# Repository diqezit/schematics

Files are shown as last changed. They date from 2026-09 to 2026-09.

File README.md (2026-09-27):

<details>
<summary><b>Русская версия README</b></summary>

# FMradio

ЧМ-приёмник на дискретных транзисторах с низкой промежуточной частотой, зарядовым частотным детектором, варикапной настройкой, автоматической подстройкой частоты и УНЧ на LM386.

- Диапазон: 88-108 МГц
- Питание: +9 В
- Нагрузка: 8 Ом
- Целевой размер платы: 50 x 70 мм
- Ток покоя тракта до УНЧ: около 23 мА

> Статус: инженерный разбор схемы и наброска печатной платы. Источник истины по номиналам и режимам - LTspice, файл `Fm.asc` (ревизия 05). Файл Multisim `Fm.ms14` сохранён как историческая ссылка предварительной серии ревизии 01 и для сверки топологии KiCad. Это не подтверждение работоспособности готового устройства и не комплект для изготовления.

Изменения ревизии 05:

1. Варикапы D1 входного контура и D5 гетеродина заменены с BB112 на BB844. Принята модель Cjo = 120 пФ, Vj = 0,75 В, M = 1,35. Расчётная кривая C(V) сверена с опорной таблицей, отклонение меньше 1 %.
2. Транзистор гетеродина 2N5401 заменён на BFT92. Для 2N5401 с fT = 300 МГц запуска на 101,9 МГц не получено из-за недостаточного запаса по граничной частоте. Для BFT92 паспортное fT равно 5 ГГц, упрощённая SPICE-модель даёт около 1 ГГц.
3. Пересчитаны контуры: L1 = 175 нГн, C3 = 4,1 пФ, C4 = 13,7 пФ; L2 = 138 нГн, C17 = 10 пФ, C18 = 36 пФ, C19 = 13,7 пФ.
4. Добавлена директива `.ic` для короткого окна звукового тракта без ожидания установления медленной петли АПЧ.
5. Нагрузка R22/C22 в АПЧ увеличена до R22 = 15 кОм и C22 = 47 мкФ. Расчётная постоянная времени составляет около 0,7 с.

Правило трёх документов. Номиналы и режимы нормативны по LTspice. Топология и посадочные места нормативны по KiCad. Расчётные формулы разделов 1-7 записаны в нумерации KiCad/README и сверяются с LTspice по таблице соответствия. Перенумерация KiCad под ревизию 05 запланирована; до её выполнения таблица соответствия нормативна.

Расчётные величины в основных разделах получены аналитически для режимов по постоянному току и RC-цепей при U_БЭ около 0,65 В и типичном h21э транзисторов. Результаты симуляции сведены в приложении, совпадения и расхождения с расчётом отмечены явно. Ни расчёт, ни симуляция не заменяют измерений на реальной плате.

## Схема

Принципиальная схема ЧМ-приёмника
Набросок схемы и платы

## Демонстрация работы

Сигнал ПЧ на выходе в симуляции

Снимок относится к одному из прогонов подгонки контуров ревизии 01 в Multisim и служит только иллюстрацией настройки. Рабочие данные ревизии 05 сняты в LTspice командой `.tran 0 12m 10m 1n`. Raw-файл или экспорт ключевых трасс следует хранить вместе с `Fm.asc`.

## Источники и воспроизводимость

- `Fm_radio.kicad_sch`: схема, KiCad 10.0, лист A3.
- `Fm_radio.kicad_pcb`: печатная плата, KiCad 10.0, два слоя меди F.Cu и B.Cu.
- `Fm_radio.kicad_pro`: настройки проекта, включая правила проверки платы.
- `Fm_radio.kicad_prl`: локальные настройки отображения.
- `Fm.asc`: файл симуляции LTspice, источник истины начиная с ревизии 02. Содержит нетлист, директивы `.tran`, `.op`, `.ic`, `.options`, модели диодов, варикапов и транзистора гетеродина.
- `Fm.ms14`: файл симуляции Multisim. Содержит экспорт предварительной серии ревизии 01 и замеры рабочей точки. Результаты ревизий 02-05 из него не воспроизводятся и не цитируются как текущие.

## Инструмент моделирования и соответствие ревизий

Начиная с ревизии 02 источником истины по номиналам и режимам является LTspice. Multisim оставлен как историческая ссылка ревизии 01 и средство сверки топологии KiCad.

LTspice выбран из-за доступных допусков интегрирования, именованных измерений, `.step`, `.meas`, `.op` и приемлемого времени расчёта. В Multisim непрерывные окна 300 мкс и 3 мс были практически недоступны, а встроенный частотомер давал ложные показания на узлах с амплитудой в десятки милливольт.

Модели LTspice, источник истины ревизии 05:

```text
.model BB844 D(Is=1e-14 Rs=0.28 N=1.0 Cjo=120p M=1.35 Vj=0.75 Fc=0.5
+ Bv=18 Ibv=10u Tt=0 Eg=1.11 Xti=3)

.model BFT92 PNP(IS=1E-14 BF=100 VAF=100 IKF=0.1 ISE=1E-13 NE=1.5
+ BR=4 IKR=0.1 ISC=1E-13 NC=1.5 RB=10 RE=1 RC=10
+ CJE=1.5P VJE=0.7 MJE=0.4 CJC=1P VJC=0.5 MJC=0.4
+ TF=0.15N TR=10N XTB=1.5 XTI=3 EG=1.11)

.model BZX55C6V8 D(Is=1e-14 N=1.1 Rs=3.5 Cjo=160p M=0.33 Vj=0.75 Bv=6.8 Ibv=5m Eg=1.11 Xti=3)
.model BZX55C3V3 D(Is=1e-14 N=1.1 Rs=15 Cjo=25p M=0.33 Vj=0.6 Bv=3.3 Ibv=5m)
```

Модель BB112 сохранена только для воспроизведения ревизии 04:

```text
.model BB112 D(Is=1e-14 Rs=0.7 N=1.2 Cjo=58p M=0.50 Vj=0.85 Fc=0.5 Bv=30 Ibv=10u Tt=0)
```

Упрощённая модель BFT92 с TF = 0,15 нс соответствует оценочному fT около 1 ГГц, а не паспортным 5 ГГц. Она подтверждает запуск в ревизии 05, но не заменяет модель производителя для оценки амплитуды, фазового шума и предельного режима. Имена библиотек остальных транзисторов и полные строки их SPICE-моделей в репозитории не зафиксированы, поэтому перед повторным прогоном модели следует сверить.

## Протокол прогонов

Нормативный короткий прогон ревизии 05:

```text
.tran 0 12m 10m 1n
.ic V(DETEC)=1.2 V(AFC)=1.2 V(FILT)=1.2 V(N010)=4.5 V(VZ_3V3)=3.3 V(VZ_6V8)=6.8
.options reltol=0.003 trtol=7 method=gear cshunt=1e-14 plotwinsize=0
```

Директива `.ic` задаёт начальные уровни детектора, АПЧ, фильтра, выхода LM386 и двух опорных шин. Она нужна для наблюдения последних 2 мс из окна 12 мс без ожидания установления петли АПЧ с постоянной времени около 0,7 с. Этот режим не доказывает захват АПЧ и не заменяет прогон без начальных условий.

Дополнительные прогоны:

- Рабочая точка: `.op` при V1 = 8/9/10 В, положении потенциометра 0/50/100 % и T = -10/25/50 C.
- ВЧ и ПЧ без принудительных начальных условий: не менее 300 мкс с максимальным шагом 1 нс.
- Звуковой тракт: не менее 20 мс либо до установления C25 = 330 мкФ и узла N010.
- АПЧ: 0,5-1 с без `.ic` или отдельная огибающая модель. Полный ВЧ-прогон с шагом 1 нс на таком интервале вычислительно тяжёл.
- Ограничитель: 3 мс с контролем VBE(VT5) не ниже -5 В и огибающей 1 кГц 280-400 мВ размаха.

## Нормативные пороги приёмки

Пороги ревизии 04 сохранены для исторического сравнения:

- меандр на коллекторе VT4 непрерывен до 300 мкс, без пачек и провалов;
- ток обратной связи УПЧ без дрейфа среднего;
- полка детектора 1,1-1,3 В;
- I(D6) 5-12 мА;
- V(REF) 6,4-7,2 В.

Нормативные пороги ревизии 05:

- размах на коллекторе Q6 1-2 В;
- ток эмиттера Q6 2-3 мА без двуполярных игл и выбросов;
- период импульсов ПЧ при MDI = 0 равен 2,35 +/- 0,05 мкс;
- полка детектора 1,1-1,3 В;
- I(D6) 5-12 мА;
- V(REF) 6,4-7,2 В;
- звуковой сигнал на нагрузке 8 Ом не меньше 1 В размаха после установления тракта.

Текущий прогон ревизии 05 проходит критерии периода ПЧ и полки детектора. Критерии амплитуды и тока гетеродина не пройдены. Ток D6 и установившиеся уровни опорных шин без `.ic` в предоставленных измерениях отсутствуют. Критерий звука не оценён, потому что V(N010) и C25 не установились в окне 12 мс.

## Блокеры до трассировки

- Перевозбуждение гетеродина. V(Q6_C) имеет размах 0-4 В, Ie(Q6) достигает примерно +/-6 мА. Требуется повторный расчёт смещения и коэффициента обратной связи BFT92. Плату до выбора проверенного режима не фиксировать.
- Сопряжение контуров. При одном управляющем напряжении разность резонансных частот L1 и L2 меняется примерно от 0,5 до 1,5 МГц вместо требуемых 425 кГц. Нужна раздельная коррекция ветвей D1 и D5 или подстроечные элементы.
- Ход настройки. Связка BB844 и 13,7 пФ в текущей модели даёт около 0,8 МГц, поэтому диапазон 88-108 МГц не перекрывается. Нужна коммутация L2, другой диапазон ёмкостей или отдельная грубая настройка.
- Сохраняется блокер ревизии 04: прогон 3 мс с VBE(VT5) не ниже -5 В ещё не выполнен.

Имена узлов вида n0XX не нормативны. Перед прогоном следует назначить метки A, B, REF, TUNE, Q1_E, Q2_B, Q3_B, Q4_C, Q5_C, Q6_C, DETEC, AFC, FILT, N010, SPK, VZ_3V3 и VZ_6V8.

## Таблица соответствия идентификаторов

Таблица нормативна до перенумерации KiCad.

| Назначение | KiCad/README | LTspice rev 05 | Номинал или тип |
|---|---|---|---|
| ВЧ-транзистор | VT1 2N5401 | Q1 2N5401 | режим без изменения |
| Смеситель | VT2 BF517 | Q2 2SC3838K | тип 2SC3838K |
| УПЧ 1 / УПЧ 2 | VT3 / VT4 BC547 | Q3 / Q4 BC547C | группа C |
| Ограничитель | VT5 BC547 | Q5 BC547C | группа C |
| Гетеродин | VT6 BFT92 | Q6 BFT92 | PNP, SOT-23 |
| Диоды детектора | VD1, VD2 1N4148 | D2, D3 1N4148 | без изменения |
| Опора настройки | VD3, R19 | D6 BZX55C6V8, R25 180 Ом | V(REF) около 6,86 В |
| Шина 3,3 В | VD4, R27 1 кОм | D4, R19 1 кОм | VZ_3V3 |
| Варикап входа | BB844, C4 13,7 пФ | D1 BB844, C4 13,7 пФ | Cjo = 120 пФ |
| Варикап гетеродина | BB844, C19 13,7 пФ | D5 BB844, C19 13,7 пФ | Cjo = 120 пФ |
| Входной контур | L1, C3, C4, D1 | L1 175 нГн, C3 4,1 пФ, C4 13,7 пФ | пересчитан в rev 05 |
| Контур гетеродина | L2, C17, C18, C19, D5 | L2 138 нГн, C17 10 пФ, C18 36 пФ, C19 13,7 пФ | пересчитан в rev 05 |
| Вход рейки | R2 22 Ом | R15 22 Ом | без изменения |
| Рейка A к рейке B | свободное обозначение | 100 Ом | номер сверить |
| Эмиттер ВЧ | R3 470 Ом | R1 470 Ом | без изменения |
| Делитель базы ВЧ | R4 6,8 кОм / R13 33 кОм | R2 6,8 кОм / R3 33 кОм | без изменения |
| База смесителя | R6 620 кОм | R4 620 кОм | без изменения |
| Нагрузка смесителя | R5 3 кОм, C3 47 пФ | R5 3 кОм, C6 47 пФ | 47 пФ обязателен |
| ФНЧ после смесителя | свободные обозначения | 470 Ом, 33 пФ NP0 | номера сверить с рейками |
| Серия после связи | R11 | R6 100 кОм | аттенюатор |
| ООС эмиттер-база | R12 | R7 2,2 кОм | слив заряда |
| Нагрузка УПЧ1 / УПЧ2 | R7 10 кОм / R8 2,2 кОм | R8 10 кОм / R9 2,2 кОм | без изменения |
| Эмиттер УПЧ2 | R14 470 Ом, C16 47 нФ | R10 470 Ом, C10 47 нФ | без изменения |
| База / нагрузка ограничителя | R9 47 кОм / R10 3 кОм | R12 47 кОм / R13 3 кОм | без изменения |
| Фильтр детектора | R15 10 кОм, C17 10 нФ | R12 10 кОм, C14 10 нФ | обозначения rev 05 |
| Связь смеситель-УПЧ | C8 | C7 1 нФ | без изменения |
| Связь УПЧ-ограничитель | C9 | C12 10 нФ | без изменения |
| Насос детектора | C10 | C13 39 пФ | без изменения |
| Потенциометр настройки | R21 10 кОм | U1 10 кОм | движок выставляется по периоду |
| АПЧ | R26/R25, C26 | R22 15 кОм, C22 47 мкФ | постоянная времени около 0,7 с |
| Выходной конденсатор УНЧ | C12 | C25 330 мкФ | время установления больше окна 12 мс |
| Байпас LM386 | по схеме | C27 | начальный заряд не установился |

Разделы 1-5 описывают тракт LTspice ревизии 05. Раздел 6 относится к модели и изделию с LM386. Раздел 7 совмещает топологию шин LTspice и требования к физической плате.

## Архитектура

```text
AE1 -> C6 -> Q1 / L1 / D1 -> Q2 -> Q3 -> Q4 -> Q5
                                                    |
                  LM386 <- volume <- detector <- D2 / D3 / C13
                    |                         |
                 C25 / 8R              R22 / C22 AFC
                                              |
                                 D1 / D5 / Q6 / L2
```

Сигнал антенны усиливается каскадом с общей базой и смешивается с сигналом гетеродина через магнитную связь L1-L2. Затем он проходит широкополосный бесконтурный усилитель промежуточной частоты, ограничивается и демодулируется зарядовым частотным детектором. Медленная составляющая напряжения детектора управляет варикапами через автоматическую подстройку частоты. Входной контур сопряжён с настройкой вторым варикапом BB844. Низкочастотный усилитель построен на LM386.

Элементная база ревизии 05: Q1 типа 2N5401, Q2 типа 2SC3838K, Q3-Q5 типа BC547C, Q6 типа BFT92, D1 и D5 типа BB844.

Промежуточная частота остаётся низкой:

```math
f_{IF} \approx 425 \text{ кГц}, \qquad f_{LO} = f_{RF} + 425 \text{ кГц}
```

При f_RF = 101,5 МГц целевая частота гетеродина равна примерно 101,925 МГц. Период 2,35 мкс соответствует 425 кГц. Источник SFFM с MDI = 75 и FS = 1 кГц даёт девиацию +/-75 кГц.

Низкая ПЧ не обеспечивает зеркальную избирательность. При верхней настройке зеркальный канал отстоит на 2f_IF, то есть примерно на 850 кГц, и остаётся внутри полосы входного контура. Для радикального улучшения нужен двухконтурный преселектор или двойное преобразование частоты.

## Шины питания

```text
+9 В -> развязка -> узел A -> развязка -> узел B
```

Узел A питает ограничитель. Узел B питает ВЧ-каскад, смеситель и усилитель промежуточной частоты. LM386 питается от +9 В с отдельной местной развязкой. Гетеродин BFT92 питается от шины VZ_3V3. Опора настройки D6 питается от +9 В через 180 Ом.

| Шина | Назначение | Нормальный уровень |
|---|---|---|
| +9 В | LM386, опорные стабилизаторы | 9,0 В |
| Узел A | ограничитель | после входной развязки |
| Узел B | Q1-Q4 | около 8,25-8,3 В |
| VZ_3V3 | Q6 BFT92 | 3,3 В |
| VZ_6V8 / REF | настройка и АПЧ | около 6,86 В |

Ток покоя около 23 мА относится к тракту до LM386. Ток и мощность полного изделия зависят от громкости и нагрузки 8 Ом.

## 1. Входной ВЧ-усилитель

Q1 2N5401 включён по схеме с общей базой. Сигнал антенны поступает на эмиттер через 1 нФ. Делитель 6,8 кОм / 33 кОм задаёт смещение базы, 10 нФ шунтирует базу по ВЧ, 470 Ом задаёт ток эмиттера. Коллектор нагружен контуром L1 = 175 нГн.

В ревизии 05 контур содержит C3 = 4,1 пФ и ветвь C4 = 13,7 пФ с D1 BB844. Обратное смещение D1 приходит с цепи настройки через резистор. Номиналы относятся к LTspice и не заменяют измерение реальной индуктивности, паразитной ёмкости и добротности.

Ёмкость модели BB844 оценивается выражением:

```math
C(V) = \frac{C_{jo}}{(1 + V/V_j)^M}, \qquad C_{jo}=120 \text{ пФ}, \quad V_j=0{,}75 \text{ В}, \quad M=1{,}35
```

Расчётная кривая сверена с опорной таблицей с отклонением меньше 1 %. Это подтверждает параметры модели, но не гарантирует сопряжение двух реальных контуров с разбросом L и паразитных ёмкостей.

Режим по постоянному току не менялся принципиально. В ревизии 05 Ie(Q1) около -1,47 мА. На эмиттере Q1 присутствует ВЧ-сигнал 101,5 МГц с размахом примерно 0-400 мВ, то есть сигнал доходит до входа смесителя.

Катушка L1 в исходной механике наматывается проводом 0,5 мм на оправке 5,5 мм. Число витков и шаг следует подобрать по измеренным 175 нГн, а не переносить автоматически из расчёта ревизии 04.

## 2. Смеситель

Q2 2SC3838K включён по схеме с общим эмиттером. Резистор 620 кОм задаёт ток базы, 3 кОм служит коллекторной нагрузкой, 47 пФ подавляет остатки ВЧ и ограничивает верхнюю частоту низкой ПЧ. Связь с усилителем промежуточной частоты идёт через разделительную цепь и аттенюатор 100 кОм.

Связь входного контура с базой смесителя должна иметь ёмкость порядка единиц пикофарад. Номинал 1 нФ из ранней схемы перегружает контур. Электролит 2,2 мкФ в ВЧ-узле исключается.

Полюс нагрузки смесителя:

```math
f_p = \frac{1}{2\pi \times 3\text{ кОм} \times 47\text{ пФ}} \approx 1{,}13 \text{ МГц}
```

Конденсатор 47 пФ обязателен. Без него остаток гетеродина выпрямляется следующим каскадом, Q3 насыщается, а тракт ПЧ защёлкивается.

В ревизии 05 V(Q2_B) меняется примерно от 350 до 900 мВ. Ic(Q2) меняется примерно от 0,3 до 3,6 мА. Смеситель работает в ключевом режиме, но инжекция гетеродина выше желаемой. Уменьшать её следует после нормализации режима Q6, а не случайным ослаблением ПЧ-тракта.

Магнитная связь L1-L2 остаётся двусторонней. Для платы требуются контролируемые ориентация и расстояние между катушками. Точное соответствие коэффициента K геометрии платы модель SPICE не рассчитывает.

### RC после смесителя

Дополнительный ФНЧ 470 Ом / 33 пФ должен стоять сразу после коллекторной нагрузки смесителя. Его расчётный полюс:

```math
f_p = \frac{1}{2\pi \times 470 \times 33\text{ пФ}} \approx 10{,}26 \text{ МГц}
```

На 425 кГц звено практически прозрачно, а остатки диапазона 88-108 МГц ослабляются. Обозначения этого фильтра конфликтовали с обозначениями развязки питания в ранних версиях и должны быть назначены заново в KiCad.

## 3. Усилитель промежуточной частоты

Q3 и Q4 BC547C образуют двухкаскадный усилитель с непосредственной связью. После связи со смесителем стоит 100 кОм, а с эмиттера Q4 на базу Q3 включён резистор 2,2 кОм. Эта пара ограничивает привод и отводит выпрямленный заряд за период ПЧ.

Эмиттер Q4 нагружен 470 Ом с шунтом 47 нФ. Связь с ограничителем идёт через 10 нФ. Номиналы усилителя промежуточной частоты в ревизии 05 не менялись.

Для периода 2,35 мкс постоянная времени слива около 2,2 мкс остаётся сопоставимой с одним циклом:

```math
\tau_{drain} \approx 2{,}2 \text{ кОм} \times 1 \text{ нФ} \approx 2{,}2 \text{ мкс}
```

Критерий работы каскада: непрерывные импульсы ПЧ без перехода в линейный режим и без дрейфа среднего тока обратной связи. Прямого отдельного набора измерений Q3/Q4 для ревизии 05 не предоставлено, поэтому прежние амплитуды ревизии 04 не объявляются текущими.

## 4. Ограничитель и детектор

Q5 BC547C работает ограничителем. Резистор 47 кОм задаёт ток базы, 3 кОм служит нагрузкой, эмиттер соединён с общим проводом. В ревизии 05 V(Q5_C) имеет прямоугольную форму 0-11 В с периодом 2,35 мкс, что соответствует ПЧ около 425 кГц.

Обратное напряжение база-эмиттер ограничителя остаётся открытым риском. Стандартная BJT-модель может не отражать реальный пробой. До прогона 3 мс с VBE(VT5) не ниже -5 В этот пункт не закрыт.

Зарядовый детектор построен на C13 = 39 пФ и двух 1N4148. Средний ток насоса оценивается так:

```math
I_{avg} = C \times \Delta U \times f_{IF}, \qquad U_{det} = I_{avg} \times R_{load}
```

При ПЧ около 425 кГц ожидаемая полка находится около 1,2 В. В ревизии 05 V(DETEC) равно 1,2 В, то есть детектор находится в штатной точке.

Фильтр ревизии 05 обозначен R12 = 10 кОм и C14 = 10 нФ. Без нагрузки:

```math
\tau_0 = 10 \text{ кОм} \times 10 \text{ нФ} = 100 \text{ мкс}
```

С нагрузкой цепи АПЧ эффективная постоянная времени оценивается примерно в 60 мкс. Вариант C14 = 4,7 нФ даёт 47 мкс без нагрузки, но не принят до проверки звуковой АЧХ и уровня пульсаций.

## 5. Гетеродин и автоматическая подстройка частоты

Q6 BFT92 с L2 = 138 нГн образует генератор Колпитца. Ёмкостная обратная связь задаётся C17 = 10 пФ и C18 = 36 пФ. Варикап D5 BB844 включён через C19 = 13,7 пФ. База заземлена по переменному току, питание приходит от стабилизированной шины 3,3 В.

Эквивалентная последовательная ёмкость делителя обратной связи:

```math
C_s = \frac{10 \times 36}{10 + 36} \approx 7{,}83 \text{ пФ}
```

2N5401 с модельным fT = 300 МГц не запускался на 101,9 МГц. BFT92 имеет паспортное fT = 5 ГГц, а применённая упрощённая модель соответствует примерно 1 ГГц. Замена восстановила запуск, но одновременно дала избыточную амплитуду.

Текущий результат:

- V(Q6_C) колеблется от 0 до 4 В;
- Ie(Q6) имеет выбросы примерно до +/-6 мА;
- период импульсов ПЧ равен 2,35 мкс;
- V(Q2_B) показывает избыточную инжекцию в смеситель.

Требуемый режим Q6 составляет 1-2 В размаха на коллекторе и 2-3 мА эмиттерного тока без выбросов. Номиналы коррекции обратной связи и смещения пока не утверждены. В исходных данных одновременно предложены несовместимые направления изменения C17 и R16, поэтому ни один вариант не считается нормативным до параметрического прогона и проверки на макете.

Цепь АПЧ содержит R22 = 15 кОм и C22 = 47 мкФ:

```math
\tau_{AFC} = 15 \text{ кОм} \times 47 \text{ мкФ} = 0{,}705 \text{ с}
```

В 12 мс V(AFC) равно 1,2009 В и практически не меняется. Это ожидаемо, потому что окно составляет меньше 2 % постоянной времени. Начальное условие V(AFC) = 1,2 В позволяет наблюдать ВЧ, ПЧ и начало звука, но не подтверждает захват и удержание АПЧ.

Знак петли при верхней настройке:

```text
f_IF растёт -> U_det растёт -> управляющее напряжение меняет C_var -> f_LO снижается -> f_IF уменьшается
```

Полярность следует подтвердить отдельным малосигнальным прогоном, потому что расположение анода и катода BB844 и знак сумматора определяют фактическое направление коррекции.

## 6. Низкочастотный усилитель

Низкочастотный усилитель выполнен на LM386 с нагрузкой 8 Ом. В отличие от ревизии 04, узлы N010 и SPK присутствуют в прогоне ревизии 05.

Выходной разделительный конденсатор C25 = 330 мкФ вместе с нагрузкой имеет оценочную постоянную времени:

```math
\tau_{out} = 8 \text{ Ом} \times 330 \text{ мкФ} \approx 2{,}64 \text{ мс}
```

Однако установление всего тракта определяется также смещением LM386, байпасом C27, фильтром и начальными условиями. В конце окна V(N010) равно 5,78 В вместо ожидаемых примерно 4,5 В, а V(SPK) имеет только около 13 мВ размаха. Эти числа относятся к переходному процессу и не являются установившейся выходной мощностью.

Критерий ревизии 05 требует не менее 1 В размаха на 8 Ом после установления. Для его проверки нужен более длинный прогон, контроль среднего V(N010), напряжения на C27 и отсутствие ограничения LM386.

На плате у LM386 обязательны 100 нФ непосредственно между выводами питания и не менее 10 мкФ местной низкочастотной развязки. Цепь Бушеро должна иметь однозначные обозначения и единицы номиналов.

## 7. Питание

Питание ВЧ-каскада, смесителя, усилителя промежуточной частоты и ограничителя следует разводить отдельными RC-звеньями. Типовое звено: 100 Ом и 100 нФ, при необходимости 10 мкФ параллельно 100 нФ. Земля каждого конденсатора возвращается к местной опорной точке каскада.

Электролитические конденсаторы из-за паразитной индуктивности не обеспечивают развязку около 100 МГц. Параллельно каждому электролиту ставится керамика 100 нФ с минимальной длиной соединений.

Источник питания в модели идеальный. Реальное проникновение импульсов LM386 в шины ВЧ и ПЧ проверяется на макете или в отдельной модели с внутренним сопротивлением источника и паразитными параметрами платы.

## Известные ограничения макета

- Зеркальный канал на расстоянии около 850 кГц архитектурой практически не подавляется.
- Текущий ход настройки около 0,8 МГц не перекрывает 88-108 МГц.
- Сопряжение L1 и L2 от одного управляющего напряжения не достигнуто: разность частот меняется примерно от 0,5 до 1,5 МГц.
- Гетеродин BFT92 перевозбуждён: V(Q6_C) 0-4 В, Ie(Q6) до примерно +/-6 мА.
- Короткая модель BFT92 соответствует примерно 1 ГГц, а не паспортным 5 ГГц, поэтому амплитуда и ток требуют проверки с моделью производителя.
- АПЧ с R22 = 15 кОм и C22 = 47 мкФ не проверена на захват и удержание без `.ic`.
- V(AFC) = 1,2009 В в окне 12 мс показывает только отсутствие заметного движения на коротком интервале.
- Звуковой выход 13 мВ снят до установления C25, C27 и рабочей точки LM386.
- V(N010) = 5,78 В вместо 4,5 В относится к переходному процессу и требует длинного прогона.
- Обратное VBE ограничителя не проверено в обязательном окне 3 мс.
- Деэмфазис с C14 = 10 нФ составляет около 60 мкс под расчётной нагрузкой, вариант 4,7 нФ не проверен.
- LM386 и питание смоделированы без всех паразитных параметров реальной платы.
- При Vz = 7,2 В и V1 = 8 В колено опорного стабилитрона может не гарантироваться.
- Нумерация KiCad, BOM и LTspice расходится; таблица соответствия нормативна до перенумерации.
- BB844 является сдвоенным варикапом в SOT-23. Использование секций и распиновка на плате должны быть сверены с конкретным исполнением.

## Приложение. Паспорт блока по симуляции

### A.0. Структура файла симуляции Multisim

Экспорт `Fm.ms14` относится к предварительной серии ревизии 01. Временные метки немонотонны, каждая строка хранит два снимка нескольких безымянных узлов, а полный временной ряд отсутствует. Длительность отдельных прогонов около 30 мкс достаточна для ВЧ и ПЧ, но недостаточна для звука и АПЧ.

| Кривая | Характерный диапазон | Историческая интерпретация |
|---|---|---|
| 1 | -7...+4 В | контур гетеродина |
| 2 | 0 В +/-1-2 мВ | анод варикапа |
| 3 | -0,7...+0,8 В | узел насоса детектора |
| 4 | 3,3-3,6 В | коллектор смесителя или УПЧ |
| 5 | 0...0,7 В | вероятный выход детектора |
| 6 | 9,000 В | идеальная шина питания |

По этому экспорту нельзя оценивать постоянные времени, установление гетеродина, дрейф частоты, звук или АПЧ. Данные ревизии 05 в `Fm.ms14` не переносятся.

### A.1. Режимы по постоянному току

| Узел / каскад | Расчёт или норма | Симуляция | Ревизия | Вывод |
|---|---|---|---|---|
| VZ_3V3 | 3,3 В | 3,3 В по `.ic`, установившееся значение отдельно не дано | 05 | опору проверить без `.ic` |
| VZ_6V8 / REF | около 6,8 В | 6,8 В по `.ic`, ранее 6,86 В | 05 / 04 | критерий 6,4-7,2 В |
| Q1 | около 1,5 мА | Ie(Q1) около -1,47 мА | 05 | режим нормальный |
| Q2 | ключевой режим | Ic(Q2) 0,3-3,6 мА | 05 | инжекция повышена |
| Q3 / Q4 | режим rev 04 без изменения номиналов | отдельных DC-данных rev 05 нет | 05 | требует `.op`-таблицы |
| Q5 | ограничение | V(Q5_C) 0-11 В | 05 | импульсы ПЧ есть |
| Q6 BFT92 | 2-3 мА по критерию | Ie(Q6) до примерно +/-6 мА | 05 | перевозбуждение |
| DETEC | 1,1-1,3 В | 1,2 В | 05 | норма |
| AFC | медленная петля | 1,2009 В за 12 мс | 05 | захват не проверен |
| N010 | около половины 9 В | 5,78 В | 05 | переходный процесс |
| SPK | не меньше 1 В размаха | около 13 мВ размаха | 05 | звук не установился |

### A.2. Замеры по переходным процессам

#### Ревизия 05, LTspice, окно 10-12 мс

| Параметр | Значение | Статус | Комментарий |
|---|---|---|---|
| Команда | `.tran 0 12m 10m 1n` | действителен | сохранены последние 2 мс |
| Вход Q1 | 0-400 мВ, 101,5 МГц | действителен | сигнал доходит до смесителя |
| Ie(Q1) | около -1,47 мА | действителен | рабочий режим |
| V(Q2_B) | 350-900 мВ | превышение | инжекция гетеродина велика |
| Ic(Q2) | 0,3-3,6 мА | действителен | ключевой режим смесителя |
| V(Q5_C) | 0-11 В | действителен | импульсы ПЧ |
| Период V(Q5_C) | 2,35 мкс | проходит | ПЧ около 425 кГц |
| V(Q6_C) | 0-4 В | не проходит | критерий 1-2 В размаха |
| Ie(Q6) | примерно +/-6 мА | не проходит | критерий 2-3 мА без выбросов |
| V(DETEC) | 1,2 В | проходит | нормальная полка |
| V(AFC) | 1,2009 В | не оценён | за 12 мс петля не устанавливается |
| V(N010) | 5,78 В | переходный | ожидаемый покой около 4,5 В |
| V(SPK) | около 13 мВ размаха | не оценён | звуковой тракт не установился |

#### Ревизия 04, LTspice, историческая рабочая точка

| Параметр | Значение | Статус |
|---|---|---|
| Центральная ПЧ | около 425 кГц | исторический |
| Период при MDI = 0 | 2,35 мкс | исторический |
| Полка детектора | 1,17-1,195 В | исторический |
| Звуковой сигнал детектора | около 360 мВ размаха | исторический |
| Инжекция на базе смесителя | 0,36-0,8 В размаха | исторический |
| Варикапы | BB112, Cjo = 58 пФ | заменены |
| Гетеродин | 2N5401 | заменён |

#### Ревизия 01, Multisim, предварительная серия

| Параметр | Значение | Статус |
|---|---|---|
| ПЧ отдельных прогонов | 250-400 кГц | исторический |
| Полка детектора | 0,40-0,50 В | исторический |
| k = 0,15 | уход 10-15 МГц | подтверждает ограничение связи |
| Запуск гетеродина | устойчивый в отдельных конфигурациях | не относится к rev 05 |

### A.3. Методика и ограничения модели

- Источник истины ревизии 05 - LTspice `Fm.asc`. Multisim используется только для истории ревизии 01.
- Частоту определяют курсорами по периоду при MDI = 0 внутри одного непрерывного участка.
- `.ic` ускоряет выход в выбранную окрестность рабочей точки, но скрывает естественный запуск медленных цепей. Все выводы об АПЧ и LM386 подтверждаются повторным прогоном без `.ic`.
- Модель BFT92 упрощена и имеет оценочное fT около 1 ГГц. Для амплитуды, тока и устойчивости требуется модель производителя и макет.
- Связь L1-L2 в SPICE задана коэффициентом K. Геометрия, экран, земля под катушками и паразитные связи платы не моделируются.
- Критерий звука применяется только после установления N010, C25 и C27.
- Для SFFM используется синтаксис `SFFM(VO VA FC MDI FS)`. При VO = 0, VA = 1m, FC = 101.5Meg, MDI = 75, FS = 1k девиация равна 75 кГц.
- B-source может задавать тот же сигнал выражением `V=0.001*sin(2*pi*101500000*time+75*sin(2*pi*1000*time))`. Утверждение о конкретном ускорении не считается нормативным без сравнения на одной машине и с одинаковыми допусками.

### A.4. Открытые вопросы

1. Калибровка гетеродина. Закрыто для точки ревизии 04. Для ревизии 05 период 2,35 мкс получен, но режим Q6 не проходит по амплитуде и току.
2. Модуляция 1 кГц в коротком окне. Частично закрыто в ревизии 04. Для ревизии 05 установившийся звук не получен.
3. Захват и удержание АПЧ, развязка УНЧ и рейки, мощность LM386 и КНИ. Открыто. Нужен длинный прогон без `.ic` или макет.
4. Измерение L1, L2 и рабочей ёмкости варикапов на конкретной плате. Открыто. Модельные 175 нГн и 138 нГн переносятся в BOM только после выбора конструкции катушек.
5. Непрерывный прогон с фиксированными параметрами. Закрыто для короткого окна ревизии 05, не закрыто для АПЧ и звука.
6. Обратное VBE ограничителя. Открыто. Нужен прогон 3 мс с VBE(VT5) не ниже -5 В.
7. Опора D6. Закрыто в ревизии 04, для ревизии 05 требуется повторный `.op` без принудительного V(VZ_6V8).
8. Устойчивость усилителя промежуточной частоты. Закрыто в ревизии 04. Для ревизии 05 номиналы не менялись, но отдельная таблица токов Q3/Q4 не снята.
9. Пульсация анода варикапа. Старое измерение BB112 не переносится на BB844. Открыто.
10. Конденсатор деэмфазиса. Текущие 10 нФ дают 100 мкс без нагрузки и около 60 мкс с расчётной нагрузкой. Выбор не закрыт.
11. Перевозбуждение гетеродина. V(Q6_C) имеет размах 0-4 В, Ie(Q6) достигает примерно +/-6 мА при критерии 1-2 В и 2-3 мА. В исходных заметках предложены C17 = 4,7 пФ или изменение R16 до 680 Ом, но обозначение R16 и направление изменения C17 описаны противоречиво. До параметрического прогона ни один номинал не принят.
12. Сопряжение контуров. При одном управляющем напряжении разность частот меняется примерно от 0,5 до 1,5 МГц вместо 0,425 МГц. Нужны раздельная коррекция D1/D5 или подстроечные элементы. Открыто.
13. Ход настройки. BB844 с C4 = C19 = 13,7 пФ даёт около 0,8 МГц по имеющимся данным и не перекрывает 88-108 МГц. Способ грубой укладки диапазона не выбран. Открыто.
14. Деэмфазис. Для R12 = 10 кОм и C14 = 10 нФ постоянная времени без нагрузки равна 100 мкс, с нагрузкой АПЧ около 60 мкс. C14 = 4,7 нФ даёт 47 мкс без нагрузки. Нужны АЧХ и измерение с фактической нагрузкой LM386. Открыто.

Замечание по обозначениям. В исходных данных критерий периода относится к коллектору VT4, а таблица ревизии 05 приводит V(Q5_C). До перенумерации следует считать нормативными частоту 425 кГц и период 2,35 мкс, а конкретную контрольную точку подтвердить по `Fm.asc` и таблице соответствия.

## Исправления к схеме и плате

1. ПЧ. Рабочая частота задаётся процедурой настройки f_LO = f_RF + 425 кГц. Период при MDI = 0 равен 2,35 +/- 0,05 мкс.
2. Катушки. Число витков, диаметр и шаг закрепляются по измеренным L1 и L2. Значения витков из ревизии 04 не гарантируют 175 нГн и 138 нГн.
3. ВЧ-связь. Электролит 2,2 мкФ исключить, связь с базой смесителя выполнить NP0/C0G номиналом порядка единиц пикофарад.
4. Конденсатор 47 пФ на коллекторе смесителя обязателен. Без него усилитель промежуточной частоты защёлкивается остатком гетеродина.
5. Эмиттер Q2. Вариант стабилизации 100-220 Ом с ВЧ-шунтом не принят без проверки.
6. Связь L1-L2. На плате нужны контролируемые ориентация и расстояние. Ёмкостную связь вместо магнитной не добавлять без отдельного расчёта.
7. Питание стабилитрона 3,3 В. Резистор 1 кОм подключается к +9 В.
8. Цепь Бушеро. Указать единицу ёмкости и присвоить уникальные обозначения.
9. Опора настройки. D6 BZX55C6V8 и R25 = 180 Ом сохраняются до повторного `.op` ревизии 05.
10. LM386. Добавить 100 нФ у выводов питания и местный электролит не менее 10 мкФ.
11. Развязка рейки от УНЧ. Проверить 100 Ом и 100 мкФ на макете с максимальной громкостью.
12. Деэмфазис. Не менять R12/C14 без измерения АЧХ и нагрузки АПЧ/LM386.
13. ВЧ-транзисторы. Q1 2N5401 остаётся предельным по fT; гетеродин переведён на BFT92.
14. Входной контур и зеркальный канал. Низкая ПЧ не даёт достаточного подавления зеркала, это ограничение архитектуры.
15. Обозначение фильтра детектора. Привести схему, BOM и плату к R12/C14 либо к другой единой паре без конфликтов.
16. ВЧ-развязка электролитов. Параллельно каждому электролиту поставить 100 нФ с коротким возвратом в землю.
17. Резистор между рейками и ФНЧ после смесителя. Назначить свободные обозначения, не пересекающиеся с АПЧ.
18. Перекрытие диапазона. Предусмотреть грубую укладку частоты, потому что электронный ход существенно меньше 20 МГц.
19. Усилитель промежуточной частоты. Сохранить 100 кОм последовательно и 2,2 кОм обратной связи, пока новый прогон не докажет другое.
20. Опора настройки D6. Питание через 180 Ом от +9 В, затем повторная установка U1 по периоду.
21. Блокирующий пункт ревизии 04. Не фиксировать плату до прогона 3 мс с контролем обратного VBE ограничителя.
22. Варикапы ревизии 05. D1 и D5 заменить на BB844 с моделью Cjo = 120 пФ, Vj = 0,75 В, M = 1,35. Для SOT-23 проверить общую катодную точку и назначение выводов. Не переносить посадочное место BB112 без проверки корпуса.
23. Гетеродин ревизии 05. Q6 заменить с 2N5401 на BFT92. Посадочное место SOT-23 и распиновку сверить с паспортом. Режим смещения и обратной связи не фиксировать до устранения тока примерно +/-6 мА.
24. Входной контур ревизии 05. Установить расчётные L1 = 175 нГн, C3 = 4,1 пФ, C4 = 13,7 пФ. Предусмотреть площадку для подстройки, потому что точное сопряжение не подтверждено.
25. Контур гетеродина ревизии 05. Установить расчётные L2 = 138 нГн, C17 = 10 пФ, C18 = 36 пФ, C19 = 13,7 пФ. Значения считать стартовыми для макета, а не гарантией перекрытия диапазона.
26. Начальные условия. Добавить директиву `.ic` только в профиль короткого прогона. Профиль проверки запуска, звука и АПЧ должен выполняться без принудительных начальных напряжений.
27. Фильтр АПЧ. Установить R22 = 15 кОм и C22 = 47 мкФ. Постоянная времени около 0,705 с. Полярность электролита и возврат земли проверить по реальному знаку напряжения.
28. Блокирующие пункты ревизии 05. До трассировки закрыть перевозбуждение Q6, сопряжение L1/L2 и способ перекрытия 88-108 МГц. Результат 13 мВ на SPK не считать отказом или приёмкой до установления LM386.

## Итоги

Ревизия 05 сохраняет архитектуру супергетеродинного ЧМ-приёмника 88-108 МГц с низкой ПЧ около 425 кГц, зарядовым детектором, варикапной настройкой, автоматической подстройкой частоты и LM386. D1 и D5 заменены на BB844, гетеродин переведён с 2N5401 на BFT92. Контуры пересчитаны на L1 = 175 нГн, C3 = 4,1 пФ, C4 = 13,7 пФ и L2 = 138 нГн, C17 = 10 пФ, C18 = 36 пФ, C19 = 13,7 пФ.

Короткий прогон подтверждает прохождение ВЧ-сигнала, ключевой режим смесителя, ПЧ около 425 кГц и полку детектора 1,2 В. Одновременно он показывает перевозбуждение BFT92: 0-4 В на коллекторе и ток до примерно +/-6 мА. АПЧ за 12 мс не успевает измениться из-за постоянной времени около 0,7 с. V(N010) = 5,78 В и V(SPK) около 13 мВ относятся к неустановившемуся звуковому тракту.

Печатная плата остаётся наброском. До её фиксации нужно нормализовать режим Q6, обеспечить сопряжение контуров, выбрать способ грубой укладки полного диапазона, проверить обратное VBE ограничителя и выполнить длинный прогон звука и АПЧ без `.ic`. Открытые вопросы перечислены в приложении A.4.

## Ссылки

- TI LM386: https://www.ti.com/product/LM386
- onsemi BC546 / BC547 / BC548: https://www.onsemi.com/pdf/datasheet/bc546-d.pdf
- onsemi 2N5401: https://www.onsemi.com/pdf/datasheet/2n5401-d.pdf
- ROHM 2SC3838K: https://www.rohm.com/products/transistors/bipolar-transistors/standard-bipolar-transistors/2sc3838k-product
- NXP BFT92: https://www.nxp.com/products/BFT92
- Infineon BB844: https://www.alldatasheet.com/datasheet-pdf/pdf/396152/INFINEON/BB844.html
- Siemens BB112, историческая модель ревизии 04: https://www.alldatasheet.com/datasheet-pdf/pdf/44230/SIEMENS/BB112.html
- Vishay BZX55: https://www.vishay.com/docs/85604/bzx55.pdf

</details>

<details>
<summary><b>English version README</b></summary>

# FMradio

FM receiver built with discrete transistors, a low intermediate frequency, a charge-pump frequency detector, varicap tuning, automatic frequency control, and an LM386 audio amplifier.

- Band: 88-108 MHz
- Supply: +9 V
- Load: 8 ohm
- Target board size: 50 x 70 mm
- Quiescent current through the detector chain: about 23 mA

> Status: engineering review of the schematic and PCB draft. The source of truth for values and operating points is LTspice, file `Fm.asc` revision 05. The Multisim file `Fm.ms14` is retained as a historical revision 01 reference and for KiCad topology checks. This is neither confirmation of a working receiver nor a fabrication-ready release.

Revision 05 changes:

1. Input-tank D1 and oscillator D5 were changed from BB112 to BB844. The model uses Cjo = 120 pF, Vj = 0.75 V, and M = 1.35. The calculated C(V) curve was checked against the reference table with less than 1 percent deviation.
2. The oscillator transistor was changed from a 2N5401 to a BFT92. The 2N5401 with fT = 300 MHz did not start at 101.9 MHz because of insufficient transition-frequency margin. The BFT92 datasheet value is 5 GHz; the simplified SPICE model gives about 1 GHz.
3. The tanks were recalculated: L1 = 175 nH, C3 = 4.1 pF, C4 = 13.7 pF; L2 = 138 nH, C17 = 10 pF, C18 = 36 pF, C19 = 13.7 pF.
4. An `.ic` directive was added for short audio-window inspection without waiting for the slow AFC loop to settle.
5. The AFC R22/C22 load was increased to R22 = 15 kOhm and C22 = 47 uF, for a calculated time constant of about 0.7 s.

Three-document rule. Values and operating points are normative from LTspice. Topology and footprints are normative from KiCad. Formulae in sections 1-7 use the KiCad/README designators and must be cross-checked against LTspice with the correspondence table. Until KiCad is renumbered for revision 05, that table is normative.

Neither calculation nor simulation replaces measurements on a real board.

## Schematic

FM receiver schematic
Schematic and PCB draft

## Demonstration

IF waveform in simulation

The image belongs to a revision 01 Multisim alignment run and is only an illustration. Revision 05 working data comes from the LTspice command `.tran 0 12m 10m 1n`. Store the raw file or exported key traces with `Fm.asc`.

## Sources and reproducibility

- `Fm_radio.kicad_sch`: KiCad 10.0 schematic, A3 sheet.
- `Fm_radio.kicad_pcb`: KiCad 10.0 two-layer PCB.
- `Fm_radio.kicad_pro`: project and DRC settings.
- `Fm_radio.kicad_prl`: local display settings.
- `Fm.asc`: LTspice simulation, source of truth from revision 02 onward. It contains the netlist, `.tran`, `.op`, `.ic`, and `.options` directives and the device models.
- `Fm.ms14`: historical Multisim revision 01 preliminary-series export. Revision 02-05 results are not reproduced from it and must not be quoted as current.

## Simulation tool and revision correspondence

From revision 02 the source of truth for values and operating points is LTspice. Multisim remains a revision 01 historical reference and a means of checking KiCad topology.

LTspice is used because it exposes integration tolerances, supports `.step`, `.meas`, `.op`, and named nodes, and completes the required windows in practical time. In Multisim, continuous 300 us and 3 ms windows were effectively unreachable, and the built-in counter produced false readings on nodes with tens-of-millivolt amplitude.

Revision 05 source-of-truth models:

```text
.model BB844 D(Is=1e-14 Rs=0.28 N=1.0 Cjo=120p M=1.35 Vj=0.75 Fc=0.5
+ Bv=18 Ibv=10u Tt=0 Eg=1.11 Xti=3)

.model BFT92 PNP(IS=1E-14 BF=100 VAF=100 IKF=0.1 ISE=1E-13 NE=1.5
+ BR=4 IKR=0.1 ISC=1E-13 NC=1.5 RB=10 RE=1 RC=10
+ CJE=1.5P VJE=0.7 MJE=0.4 CJC=1P VJC=0.5 MJC=0.4
+ TF=0.15N TR=10N XTB=1.5 XTI=3 EG=1.11)

.model BZX55C6V8 D(Is=1e-14 N=1.1 Rs=3.5 Cjo=160p M=0.33 Vj=0.75 Bv=6.8 Ibv=5m Eg=1.11 Xti=3)
.model BZX55C3V3 D(Is=1e-14 N=1.1 Rs=15 Cjo=25p M=0.33 Vj=0.6 Bv=3.3 Ibv=5m)
```

The BB112 model is retained only to reproduce revision 04:

```text
.model BB112 D(Is=1e-14 Rs=0.7 N=1.2 Cjo=58p M=0.50 Vj=0.85 Fc=0.5 Bv=30 Ibv=10u Tt=0)
```

The simplified BFT92 model with TF = 0.15 ns represents an approximate fT near 1 GHz rather than the 5 GHz datasheet value. It is adequate to demonstrate startup but not to certify amplitude, phase noise, or the limiting regime. Library names and the full SPICE model lines of the remaining transistors are not pinned in the repository, so the models must be re-checked before any repeat run.

Position numbers and some values in the LTspice revision do not match the KiCad schematic or the text of sections 1-7. Any number moved between documents must be cross-checked against the correspondence table. Before routing, bring the schematic, BOM, and PCB to one numbering.

## Run protocol

Normative short revision 05 run:

```text
.tran 0 12m 10m 1n
.ic V(DETEC)=1.2 V(AFC)=1.2 V(FILT)=1.2 V(N010)=4.5 V(VZ_3V3)=3.3 V(VZ_6V8)=6.8
.options reltol=0.003 trtol=7 method=gear cshunt=1e-14 plotwinsize=0
```

The `.ic` directive places the detector, AFC, filter, LM386 output, and reference rails near the intended operating point so the final 2 ms of a 12 ms run can be inspected. It does not prove natural startup, AFC capture, or full audio settling.

Additional runs:

- `.op` at V1 = 8/9/10 V, tuning control 0/50/100 percent, T = -10/25/50 C.
- RF and IF without forced initial conditions: at least 300 us with a maximum step of 1 ns.
- Audio: at least 20 ms or until C25, C27, and N010 settle.
- AFC: 0.5-1 s without `.ic`, or a separate envelope model.
- Limiter: 3 ms with VBE(VT5) no lower than -5 V and a 1 kHz envelope of 280-400 mV pp.

## Normative acceptance thresholds

Revision 04 thresholds are kept for historical comparison:

- the square wave at the VT4 collector is continuous to 300 us, with no bursts or dropouts;
- the IF feedback current shows no drift of its mean;
- detector plateau 1.1-1.3 V;
- I(D6) 5-12 mA;
- V(REF) 6.4-7.2 V.

Revision 05 thresholds:

- Q6 collector amplitude 1-2 V pp;
- Q6 emitter current 2-3 mA without bipolar spikes;
- IF pulse period at MDI = 0 equal to 2.35 +/- 0.05 us;
- detector plateau 1.1-1.3 V;
- I(D6) 5-12 mA;
- V(REF) 6.4-7.2 V;
- audio at the settled 8 ohm load at least 1 V pp.

The current run passes the IF period and detector plateau criteria. It fails the oscillator amplitude and current criteria. D6 current and settled reference-rail levels without `.ic` are not present in the supplied measurements. Audio is not assessed because N010 and C25 did not settle in the 12 ms window.

## Blocking items before routing

- Oscillator overdrive. V(Q6_C) is 0-4 V and Ie(Q6) reaches about +/-6 mA. Do not freeze the board before the BFT92 bias and feedback ratio are corrected and verified.
- Tank tracking. With one tuning voltage the L1-L2 frequency difference changes from about 0.5 to 1.5 MHz instead of remaining at 425 kHz. Independent correction or trimmers are required.
- Tuning travel. The present BB844 and 13.7 pF network gives about 0.8 MHz and cannot cover 88-108 MHz. Coarse tuning, switched L2, or another capacitance range is required.
- The revision 04 limiter blocker remains open: a 3 ms run with VBE(VT5) no lower than -5 V has not been completed.

Node names of the n0XX form are not normative. Before a run, assign the labels A, B, REF, TUNE, Q1_E, Q2_B, Q3_B, Q4_C, Q5_C, Q6_C, DETEC, AFC, FILT, N010, SPK, VZ_3V3, and VZ_6V8.

## Identifier correspondence table

The table is normative until KiCad is renumbered.

| Function | KiCad/README | LTspice rev 05 | Value or type |
|---|---|---|---|
| RF transistor | VT1 2N5401 | Q1 2N5401 | unchanged bias |
| Mixer | VT2 | Q2 2SC3838K | switching mixer |
| IF amplifier | VT3 / VT4 | Q3 / Q4 BC547C | group C |
| Limiter | VT5 | Q5 BC547C | group C |
| Oscillator | VT6 BFT92 | Q6 BFT92 | PNP, SOT-23 |
| Detector diodes | VD1 / VD2 | D2 / D3 1N4148 | unchanged |
| Tuning reference | VD3 / R19 | D6 BZX55C6V8 / R25 180 ohm | about 6.86 V |
| 3.3 V rail | VD4 / R27 | D4 / R19 1 kOhm | VZ_3V3 |
| Input varicap | BB844 / C4 | D1 BB844 / C4 13.7 pF | Cjo = 120 pF |
| Oscillator varicap | BB844 / C19 | D5 BB844 / C19 13.7 pF | Cjo = 120 pF |
| Input tank | L1 / C3 / C4 / D1 | 175 nH / 4.1 pF / 13.7 pF / BB844 | rev 05 |
| Oscillator tank | L2 / C17 / C18 / C19 / D5 | 138 nH / 10 pF / 36 pF / 13.7 pF / BB844 | rev 05 |
| Mixer load | 3 kOhm / 47 pF | R5 / C6 | 47 pF mandatory |
| IF attenuator | series resistor | R6 100 kOhm | unchanged |
| IF feedback | emitter-to-base | R7 2.2 kOhm | unchanged |
| Detector filter | R12 / C14 | 10 kOhm / 10 nF | rev 05 names |
| AFC | R22 / C22 | 15 kOhm / 47 uF | about 0.705 s |
| LM386 output capacitor | output coupling | C25 330 uF | settling exceeds short window |
| LM386 bypass | bypass node | C27 | not settled in the current run |

Sections 1-5 describe the LTspice revision 05 chain. Section 6 covers the LM386 stage in both the model and the product. Section 7 combines the LTspice rail topology with requirements that apply to the physical board.

## Architecture

```text
AE1 -> C6 -> Q1 / L1 / D1 -> Q2 -> Q3 -> Q4 -> Q5
                                                    |
                  LM386 <- volume <- detector <- D2 / D3 / C13
                    |                         |
                 C25 / 8R              R22 / C22 AFC
                                              |
                                 D1 / D5 / Q6 / L2
```

The antenna signal is amplified by a common-base RF stage and mixed with the oscillator through magnetic coupling between L1 and L2. The wideband untuned IF chain is followed by a limiter and a charge-pump frequency detector. The slow detector component drives the two BB844 tuning branches through AFC. The audio amplifier is an LM386.

Revision 05 parts are Q1 2N5401, Q2 2SC3838K, Q3-Q5 BC547C, Q6 BFT92, and D1/D5 BB844.

```math
f_{IF} \approx 425 \text{ kHz}, \qquad f_{LO} = f_{RF} + 425 \text{ kHz}
```

At 101.5 MHz RF the target oscillator is about 101.925 MHz. A 2.35 us period represents 425 kHz. The low IF places the image only about 850 kHz away, inside the front-end bandwidth. Better image rejection requires a two-tank preselector or dual conversion.

## Power rails

Node A feeds the limiter. Node B feeds Q1-Q4. The LM386 uses +9 V with local decoupling. The BFT92 oscillator uses VZ_3V3. The tuning reference uses the 6.8 V zener fed from +9 V through 180 ohm.

| Rail | Function | Normal level |
|---|---|---|
| +9 V | LM386 and references | 9.0 V |
| Node A | limiter | after input decoupling |
| Node B | Q1-Q4 | about 8.25-8.3 V |
| VZ_3V3 | BFT92 oscillator | 3.3 V |
| VZ_6V8 / REF | tuning and AFC | about 6.86 V |

The quiescent current of about 23 mA refers to the chain ahead of the LM386. Total product current and dissipation depend on volume setting and on the 8 ohm load.

## 1. Input RF amplifier

Q1 is a common-base 2N5401 stage. The antenna signal enters the emitter through 1 nF. A 6.8 kOhm / 33 kOhm divider sets base bias, 10 nF bypasses the base at RF, and 470 ohm sets the emitter current. The collector is loaded by the tank.

The revision 05 tank is L1 = 175 nH with C3 = 4.1 pF and the C4 = 13.7 pF plus D1 BB844 branch. The D1 reverse bias comes from the tuning network through a series resistor. These values are LTspice values and do not replace measurement of the real inductance, parasitic capacitance, and loaded Q.

```math
C(V) = \frac{C_{jo}}{(1 + V/V_j)^M}, \qquad C_{jo}=120 \text{ pF}, \quad V_j=0.75 \text{ V}, \quad M=1.35
```

The model curve was checked against the reference table to within 1 percent. Real tracking still depends on inductance, parasitic capacitance, and component spread.

In revision 05 Ie(Q1) is about -1.47 mA. V(Q1_E) carries a 101.5 MHz signal from 0 to about 400 mV, confirming delivery to the mixer input.

Coil L1 is wound with 0.5 mm wire on a 5.5 mm mandrel. Turn count and pitch must be chosen from a measured 175 nH rather than copied from the revision 04 calculation.

## 2. Mixer

Q2 is a 2SC3838K common-emitter switching mixer. A 620 kOhm resistor sets base current, 3 kOhm is the collector load, and 47 pF suppresses RF residue while setting the upper bound of the low IF. The IF leaves through a coupling network and a 100 kOhm attenuator.

```math
f_p = \frac{1}{2\pi \times 3\text{ kOhm} \times 47\text{ pF}} \approx 1.13 \text{ MHz}
```

The 47 pF capacitor is mandatory because it prevents LO residue from latching the IF amplifier. The debug signature of its absence is a Q3 collector below 0.3 V with the oscillator running.

Revision 05 V(Q2_B) is about 350-900 mV and Ic(Q2) about 0.3-3.6 mA. The mixer switches, but oscillator injection is excessive. Correct Q6 before changing the IF attenuation.

The input-tank coupling capacitor must be in the single-pF range. The historical 1 nF value and a 2.2 uF electrolytic on the RF node must not be fitted.

Magnetic L1-L2 coupling remains bidirectional. The board needs controlled coil orientation and spacing. SPICE does not derive the coupling coefficient from board geometry.

### Mixer post-filter

An additional low-pass section of 470 ohm and 33 pF belongs immediately after the mixer collector load:

```math
f_p = \frac{1}{2\pi \times 470 \times 33\text{ pF}} \approx 10.26 \text{ MHz}
```

It is nearly transparent at 425 kHz while reducing residual 88-108 MHz energy on the way into the IF amplifier. Its designators clashed with supply-decoupling parts in earlier versions and must be reassigned in KiCad.

## 3. IF amplifier

Q3 and Q4 remain the directly coupled BC547C pair. The 100 kOhm series attenuator and 2.2 kOhm emitter-to-base feedback resistor are retained. The Q4 emitter uses 470 ohm bypassed by 47 nF, and 10 nF couples to the limiter.

The 100 kOhm and 2.2 kOhm pair limits the drive and drains rectified charge within one IF cycle:

```math
\tau_{drain} \approx 2.2 \text{ kOhm} \times 1 \text{ nF} \approx 2.2 \text{ us}
```

That is shorter than the 2.35 us IF period, so charge does not accumulate on the coupling capacitor.

Revision 05 does not provide a separate Q3/Q4 DC table, so revision 04 amplitudes are not relabelled as current. Acceptance requires continuous IF pulses, no transition into a linear waveform, and no drift of the feedback-current mean.

## 4. Limiter and detector

Q5 is a BC547C limiter. A 47 kOhm resistor sets base current, 3 kOhm is the load, and the emitter returns to ground. Revision 05 V(Q5_C) is a 0-11 V pulse waveform with a 2.35 us period, corresponding to about 425 kHz.

Limiter reverse base-emitter voltage remains an open risk. A standard BJT model may not represent the real breakdown, so the item stays open until the 3 ms run with VBE(VT5) no lower than -5 V is complete.

The charge-pump detector uses C13 = 39 pF and two 1N4148 diodes:

```math
I_{avg} = C \times \Delta U \times f_{IF}, \qquad U_{det} = I_{avg} \times R_{load}
```

At about 425 kHz the expected plateau is near 1.2 V. V(DETEC) is 1.2 V and passes the 1.1-1.3 V criterion.

The revision 05 filter uses R12 = 10 kOhm and C14 = 10 nF:

```math
\tau_0 = 10 \text{ kOhm} \times 10 \text{ nF} = 100 \text{ us}
```

Under AFC loading the effective value is estimated near 60 us. A 4.7 nF alternative gives 47 us unloaded, but it is not adopted before the audio response and ripple level are measured.

## 5. Local oscillator and AFC

Q6 BFT92, L2 = 138 nH, C17 = 10 pF, C18 = 36 pF, D5 BB844, and C19 = 13.7 pF form the revision 05 Colpitts oscillator. The base is AC-grounded and the stage is fed from the regulated 3.3 V rail.

```math
C_s = \frac{10 \times 36}{10 + 36} \approx 7.83 \text{ pF}
```

The 2N5401 did not start at 101.9 MHz. The BFT92 starts, but V(Q6_C) is 0-4 V and Ie(Q6) reaches about +/-6 mA. The required values are 1-2 V pp and 2-3 mA without spikes. No correction value is normative yet because the supplied notes conflict on the direction and designator of the proposed C17/R16 changes.

The AFC network is R22 = 15 kOhm and C22 = 47 uF:

```math
\tau_{AFC} = 15 \text{ kOhm} \times 47 \text{ uF} = 0.705 \text{ s}
```

V(AFC) remains at 1.2009 V in 12 ms, as expected for such a slow loop, because the window is less than 2 percent of the time constant. The `.ic` value of 1.2 V supports short-window inspection but cannot demonstrate capture or hold.

Loop sign with high-side tuning:

```text
f_IF rises -> U_det rises -> control voltage changes C_var -> f_LO falls -> f_IF falls
```

The polarity must be confirmed by a dedicated small-signal run, because the BB844 orientation and the summing-node sign determine the actual correction direction.

## 6. Audio amplifier

Unlike revision 04, the LM386 and the nodes N010 and SPK are present in the revision 05 run. C25 = 330 uF couples the output to the 8 ohm load:

```math
\tau_{out} = 8 \text{ ohm} \times 330 \text{ uF} \approx 2.64 \text{ ms}
```

Total settling also depends on LM386 bias, the C27 bypass, the filter, and the initial conditions.

At the end of the current run V(N010) is 5.78 V rather than the expected value near 4.5 V, and V(SPK) is only about 13 mV pp. C25, C27, and the LM386 bias have not settled. These values are transitional and are not an output-power result.

Acceptance requires at least 1 V pp at 8 ohm after settling. The board requires 100 nF directly at the LM386 supply pins, local electrolytic decoupling, and an unambiguous Boucherot network value.

## 7. Power supply

RF, mixer, IF, limiter, and LM386 supply paths require local RC decoupling. A practical starting point is 100 ohm with 100 nF, with 10 uF in parallel where low-frequency isolation is required. Each capacitor ground returns to the local reference point of its own stage.

Electrolytic capacitors do not decouple near 100 MHz because of their parasitic inductance. Every electrolytic needs a 100 nF ceramic beside it with the shortest possible connections.

The simulation uses an ideal supply. Real LM386 pulse ingress into the RF and IF rails must be checked on hardware or with a separate model that includes source impedance and board parasitics.

## Known prototype limitations

- The image about 850 kHz away is effectively unrejected.
- Present tuning travel is about 0.8 MHz, far short of 88-108 MHz.
- L1/L2 tracking from one control voltage is not achieved.
- The BFT92 oscillator is overdriven at 0-4 V and about +/-6 mA.
- The simplified BFT92 model represents about 1 GHz rather than the 5 GHz datasheet value.
- AFC capture and hold have not been tested without `.ic`.
- Audio remains unsettled at 13 mV pp in the 12 ms run.
- N010 remains at 5.78 V during the observed transition.
- Limiter reverse VBE has not been verified in the required 3 ms run.
- De-emphasis is about 60 us under the estimated load; 4.7 nF remains open.
- The ideal supply and incomplete parasitic model do not represent the PCB.
- KiCad, BOM, and LTspice designators still diverge.
- V(AFC) = 1.2009 V in the 12 ms window only shows the absence of visible movement on a short interval.
- At Vz = 7.2 V and V1 = 8 V the reference zener knee may not be guaranteed.
- BB844 is a dual varicap in SOT-23. Section usage and pin assignment must match the specific part variant.
- The BB844 SOT-23 common-cathode pinout must be checked before footprint release.

## Appendix. Simulation datasheet

### A.0. Multisim file structure

`Fm.ms14` contains non-monotonic, two-snapshot records from separate revision 01 runs. Each row holds several unnamed nodes at two moments, and no complete time series is stored. Individual run length of about 30 us is enough for RF and IF waveforms but not for audio or AFC.

| Trace | Signature | Historical interpretation |
|---|---|---|
| 1 | -7...+4 V | oscillator tank |
| 2 | 0 V +/-1-2 mV | varicap anode |
| 3 | -0.7...+0.8 V | detector pump node |
| 4 | 3.3-3.6 V | mixer or IF collector |
| 5 | 0...0.7 V | probable detector output |
| 6 | 9.000 V | ideal supply rail |

The export cannot support time-constant, settling, drift, audio, or AFC conclusions. No revision 05 number is to be copied into it.

### A.1. DC and slow-node status

| Node or stage | Expected | Revision 05 result | Verdict |
|---|---|---|---|
| VZ_3V3 | 3.3 V | 3.3 V by `.ic`, settled value not supplied | check without `.ic` |
| VZ_6V8 / REF | about 6.8 V | 6.8 V by `.ic`, 6.86 V in revision 04 | criterion 6.4-7.2 V |
| Q1 | about 1.5 mA | Ie about -1.47 mA | normal |
| Q2 | switching | Ic 0.3-3.6 mA | high injection |
| Q3 / Q4 | revision 04 values unchanged | no revision 05 DC data | needs an `.op` table |
| Q5 | limiting | collector 0-11 V | IF pulses present |
| Q6 | 2-3 mA | about +/-6 mA spikes | fail |
| DETEC | 1.1-1.3 V | 1.2 V | pass |
| AFC | slow loop | 1.2009 V at 12 ms | not assessed |
| N010 | near half supply | 5.78 V | transitional |
| SPK | at least 1 V pp | about 13 mV pp | not settled |

### A.2. Transient measurements

#### Revision 05, LTspice, 10-12 ms saved window

| Parameter | Value | Status | Note |
|---|---|---|---|
| Command | `.tran 0 12m 10m 1n` | valid | last 2 ms saved |
| Q1 emitter signal | 0-400 mV at 101.5 MHz | valid | RF reaches mixer |
| Ie(Q1) | about -1.47 mA | valid | normal bias |
| V(Q2_B) | 350-900 mV | excessive | LO injection |
| Ic(Q2) | 0.3-3.6 mA | valid | switching mode |
| V(Q5_C) | 0-11 V | valid | IF pulse waveform |
| Q5_C period | 2.35 us | pass | about 425 kHz |
| V(Q6_C) | 0-4 V | fail | target 1-2 V pp |
| Ie(Q6) | about +/-6 mA | fail | target 2-3 mA |
| V(DETEC) | 1.2 V | pass | normal plateau |
| V(AFC) | 1.2009 V | not assessed | loop is much slower than 12 ms |
| V(N010) | 5.78 V | transitional | not at about 4.5 V |
| V(SPK) | about 13 mV pp | not assessed | audio not settled |

#### Revision 04, LTspice, historical operating point

| Parameter | Value | Status |
|---|---|---|
| Centre IF | about 425 kHz | historical |
| Period at MDI = 0 | 2.35 us | historical |
| Detector plateau | 1.17-1.195 V | historical |
| Detector audio | about 360 mV pp | historical |
| Injection at the mixer base | 0.36-0.8 V pp | historical |
| Varicaps | BB112, Cjo = 58 pF | replaced |
| Oscillator | 2N5401 | replaced |

#### Revision 01, Multisim, preliminary series

| Parameter | Value | Status |
|---|---|---|
| IF of individual runs | 250-400 kHz | historical |
| Detector plateau | 0.40-0.50 V | historical |
| k = 0.15 | 10-15 MHz pulling | confirms the coupling limit |
| Oscillator startup | reliable in some configurations | not applicable to revision 05 |

### A.3. Method and model limits

- `Fm.asc` is the revision 05 source of truth. Multisim is used only for revision 01 history.
- Measure frequency by cursor period at MDI = 0 inside one continuous segment.
- `.ic` is only a short-run aid. AFC and audio conclusions require a run without forced initial conditions.
- The BFT92 model is simplified and must be cross-checked against a manufacturer model and hardware.
- SPICE K coupling does not model coil geometry, shielding, copper, or layout parasitics.
- Apply the audio threshold only after N010, C25, and C27 settle.
- The SFFM syntax is `SFFM(VO VA FC MDI FS)`. With VO = 0, VA = 1m, FC = 101.5Meg, MDI = 75, and FS = 1k the deviation is 75 kHz.
- An equivalent B-source expression is `V=0.001*sin(2*pi*101500000*time+75*sin(2*pi*1000*time))`. Any claim about a specific speed-up is not normative without a comparison on one machine with identical tolerances.

### A.4. Open items

1. Oscillator calibration is closed for the revision 04 point. Revision 05 reaches the target period but fails oscillator amplitude and current.
2. The 1 kHz short-window detector result was closed in revision 04. Settled revision 05 audio is still open.
3. AFC capture and hold, audio-rail isolation, LM386 power, and THD remain open.
4. Physical L1, L2, and BB844 capacitance measurement remains open.
5. The short continuous revision 05 run is complete; long AFC and audio runs are not.
6. Limiter reverse VBE remains open. Run 3 ms and require VBE(VT5) no lower than -5 V.
7. D6 was closed in revision 04. Repeat `.op` for revision 05 without forcing VZ_6V8.
8. IF stability was closed in revision 04. A revision 05 Q3/Q4 current table is still missing.
9. BB844 anode ripple is open. BB112 results cannot be reused.
10. The de-emphasis capacitor remains open. Current 10 nF gives 100 us unloaded and about 60 us under the estimated load.
11. Oscillator overdrive. V(Q6_C) is 0-4 V and Ie(Q6) reaches about +/-6 mA against limits of 1-2 V and 2-3 mA. The notes propose C17 = 4.7 pF or changing R16 to 680 ohm, but the R16 designator and the direction of the C17 change conflict. No correction is accepted before a parameter sweep.
12. Tank tracking. The single-control frequency difference changes from about 0.5 to 1.5 MHz instead of 0.425 MHz. Independent D1/D5 correction or trimmers are required.
13. Tuning travel. BB844 with C4 = C19 = 13.7 pF gives about 0.8 MHz in the available data and cannot cover 88-108 MHz. The coarse-tuning method is not selected.
14. De-emphasis. R12 = 10 kOhm and C14 = 10 nF give 100 us unloaded and about 60 us with AFC loading. C14 = 4.7 nF gives 47 us unloaded. Measure the response with the actual LM386 load.

Designator note. The supplied acceptance text names the VT4 collector, while the revision 05 measurement names Q5_C. Until renumbering is complete, the normative quantities are the 425 kHz IF and 2.35 us period; verify the physical probe node in `Fm.asc`.

## Schematic and PCB corrections

1. Set the IF by the procedure f_LO = f_RF + 425 kHz and a 2.35 +/- 0.05 us period at MDI = 0.
2. Select winding geometry from measured L1 and L2. Revision 04 turn counts do not guarantee 175 nH and 138 nH.
3. Remove the 2.2 uF RF-node electrolytic and use a single-pF NP0/C0G mixer coupling capacitor.
4. Keep the 47 pF mixer-collector shunt.
5. Do not adopt Q2 emitter degeneration before it is simulated and measured.
6. Control L1-L2 orientation and spacing. Do not add arbitrary capacitive LO coupling.
7. Feed the 3.3 V zener resistor from +9 V.
8. Give the Boucherot capacitor a unit and unique designator.
9. Retain D6 BZX55C6V8 and 180 ohm pending a revision 05 `.op` run.
10. Add 100 nF at LM386 supply pins and at least 10 uF local decoupling.
11. Verify stronger audio-rail isolation at maximum volume.
12. Do not change R12/C14 without measuring the loaded audio response.
13. Retain 2N5401 at Q1 only with RF verification; Q6 is now BFT92.
14. Treat poor image rejection as an architecture limit.
15. Unify the detector-filter designators across schematic, BOM, and PCB.
16. Fit 100 nF beside every decoupling electrolytic.
17. Assign unique designators to the rail isolation and mixer post-filter parts.
18. Add a coarse band-placement mechanism because electronic travel is far below 20 MHz.
19. Retain the 100 kOhm IF attenuator and 2.2 kOhm feedback resistor.
20. Feed D6 through 180 ohm from +9 V and recalibrate U1 by period.
21. Do not freeze the board before the 3 ms limiter reverse-VBE run passes.
22. Replace D1 and D5 with BB844 using Cjo = 120 pF, Vj = 0.75 V, and M = 1.35. Verify the SOT-23 common-cathode pinout and footprint.
23. Replace oscillator Q6 with BFT92. Verify SOT-23 pinout and do not freeze bias or feedback before removing the approximately +/-6 mA overdrive.
24. Start the input tank with L1 = 175 nH, C3 = 4.1 pF, and C4 = 13.7 pF. Provide an alignment option.
25. Start the oscillator tank with L2 = 138 nH, C17 = 10 pF, C18 = 36 pF, and C19 = 13.7 pF. These are prototype starting values, not guaranteed band coverage.
26. Use `.ic` only in the short-run profile. Startup, audio, and AFC profiles must also run without forced initial voltages.
27. Fit R22 = 15 kOhm and C22 = 47 uF in the AFC filter. Verify electrolytic polarity and ground return.
28. Before routing, close Q6 overdrive, L1/L2 tracking, and full-band coverage. Do not classify the 13 mV SPK result before the LM386 settles.

## Summary

Revision 05 retains the 88-108 MHz low-IF superheterodyne architecture with a roughly 425 kHz IF, charge-pump detector, varicap tuning, AFC, and LM386 audio. D1 and D5 are now BB844 and the oscillator is now a BFT92. The tanks use L1 = 175 nH, C3 = 4.1 pF, C4 = 13.7 pF and L2 = 138 nH, C17 = 10 pF, C18 = 36 pF, C19 = 13.7 pF.

The short run confirms RF delivery, switching mixer operation, a roughly 425 kHz IF, and a 1.2 V detector plateau. It also shows BFT92 overdrive at 0-4 V and about +/-6 mA. AFC cannot settle in 12 ms with a 0.705 s time constant. N010 at 5.78 V and SPK near 13 mV are transitional audio results.

The PCB remains a draft. Before release, correct Q6 bias, solve tank tracking, provide coarse full-band tuning, verify limiter reverse VBE, and run audio and AFC without `.ic`. Open items are listed in Appendix A.4.

## References

- TI LM386: https://www.ti.com/product/LM386
- onsemi BC546 / BC547 / BC548: https://www.onsemi.com/pdf/datasheet/bc546-d.pdf
- onsemi 2N5401: https://www.onsemi.com/pdf/datasheet/2n5401-d.pdf
- ROHM 2SC3838K: https://www.rohm.com/products/transistors/bipolar-transistors/standard-bipolar-transistors/2sc3838k-product
- NXP BFT92: https://www.nxp.com/products/BFT92
- Infineon BB844: https://www.alldatasheet.com/datasheet-pdf/pdf/396152/INFINEON/BB844.html
- Siemens BB112, revision 04 historical model: https://www.alldatasheet.com/datasheet-pdf/pdf/44230/SIEMENS/BB112.html
- Vishay BZX55: https://www.vishay.com/docs/85604/bzx55.pdf

</details>

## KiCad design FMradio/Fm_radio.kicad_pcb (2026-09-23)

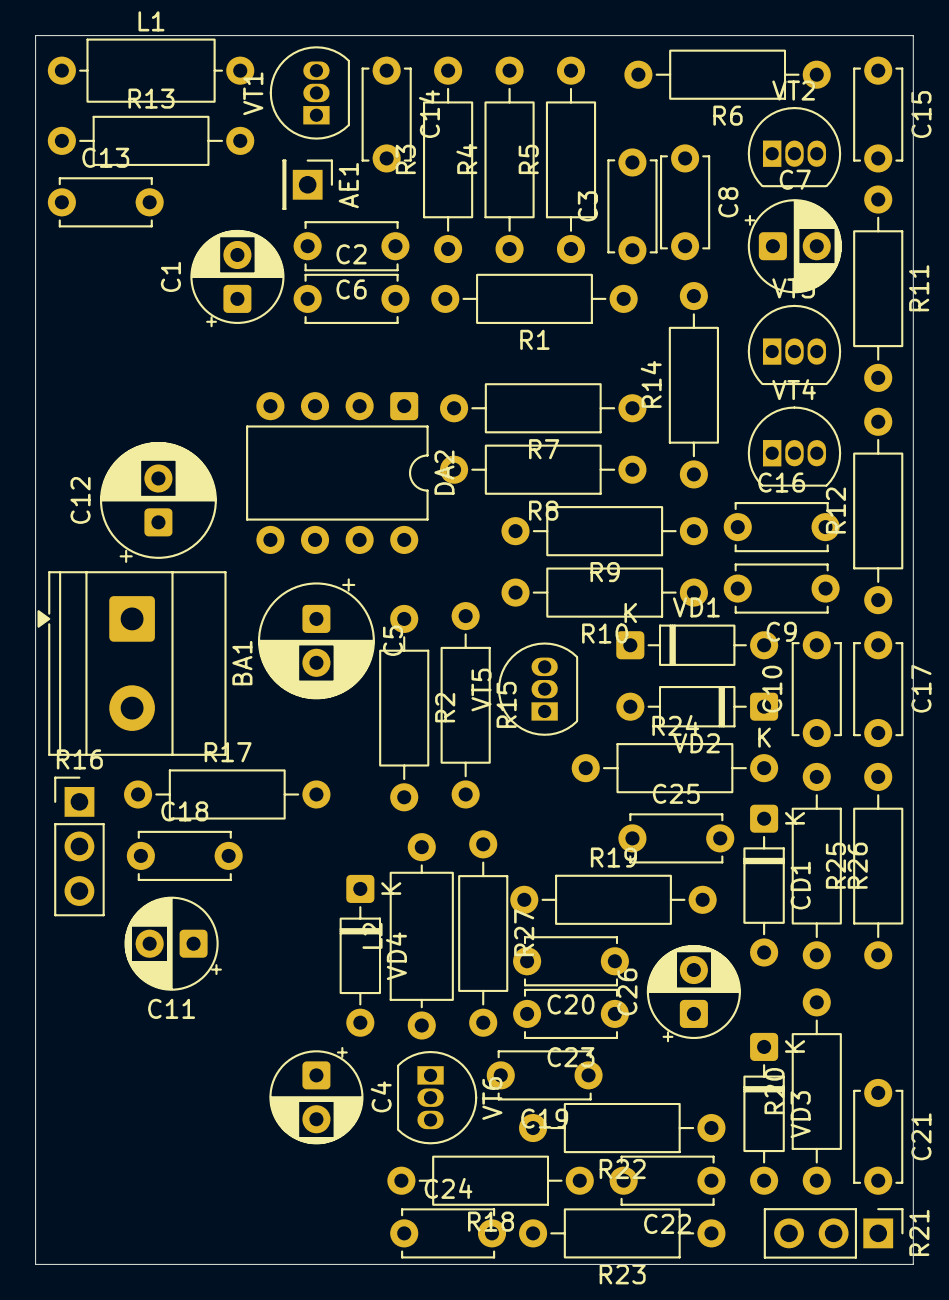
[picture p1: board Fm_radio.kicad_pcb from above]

Board: 2 copper layers, 50.0 x 70.0 mm, 69 parts (0 on the bottom side), 32 nets, no tracks yet.

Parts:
AE1: Antenna; PinHeader_1x01_P2.54mm_Vertical
BA1: 8R; TerminalBlock_Phoenix_MKDS-1,5-2-5.08_1x02_P5.08mm_Horizont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
C1, C7: 10u; CP_Radial_D5.0mm_P2.50mm
C2, C21, C24, C25: 100n; C_Disc_D5.0mm_W2.5mm_P5.00mm
C3: 47; C_Disc_D5.0mm_W2.5mm_P5.00mm
C4, C11: 22u; CP_Radial_D5.0mm_P2.50mm
C5, C12: 220u; CP_Radial_D6.3mm_P2.50mm
C6, C15, C20: 1n; C_Disc_D5.0mm_W2.5mm_P5.00mm
C8, C9: 3.3n; C_Disc_D5.0mm_W2.5mm_P5.00mm
C10: 39; C_Disc_D5.0mm_W2.5mm_P5.00mm
C13, C17, C22: 10n; C_Disc_D5.0mm_W2.5mm_P5.00mm
C14: 8/30pF; C_Disc_D5.0mm_W2.5mm_P5.00mm
C16: 47n; C_Disc_D5.0mm_W2.5mm_P5.00mm
C18: 0.1; C_Disc_D5.0mm_W2.5mm_P5.00mm
C19: 8.2p; C_Disc_D5.0mm_W2.5mm_P5.00mm
C23: 36; C_Disc_D5.0mm_W2.5mm_P5.00mm
C26: 4.7u; CP_Radial_D5.0mm_P2.50mm
CD1: BB910; D_DO-35_SOD27_P7.62mm_Horizontal
DA2: LM386; DIP-8_W7.62mm
L1: 6T; L_Axial_L7.0mm_D3.3mm_P10.16mm_Horizontal_Fastron_MICC
L2: 5T; L_Axial_L7.0mm_D3.3mm_P10.16mm_Horizontal_Fastron_MICC
R1, R27: 1k; R_Axial_DIN0207_L6.3mm_D2.5mm_P10.16mm_Horizontal
R2: 22; R_Axial_DIN0207_L6.3mm_D2.5mm_P10.16mm_Horizontal
R3, R14, R19: 470; R_Axial_DIN0207_L6.3mm_D2.5mm_P10.16mm_Horizontal
R4: 6.8k; R_Axial_DIN0207_L6.3mm_D2.5mm_P10.16mm_Horizontal
R5, R10: 3k; R_Axial_DIN0207_L6.3mm_D2.5mm_P10.16mm_Horizontal
R6: 620; R_Axial_DIN0207_L6.3mm_D2.5mm_P10.16mm_Horizontal
R7, R15, R22: 10k; R_Axial_DIN0207_L6.3mm_D2.5mm_P10.16mm_Horizontal
R8: 2.2k; R_Axial_DIN0207_L6.3mm_D2.5mm_P10.16mm_Horizontal
R9: 47k; R_Axial_DIN0207_L6.3mm_D2.5mm_P10.16mm_Horizontal
R11: 33; R_Axial_DIN0207_L6.3mm_D2.5mm_P10.16mm_Horizontal
R12: 100k; R_Axial_DIN0207_L6.3mm_D2.5mm_P10.16mm_Horizontal
R13: 33k; R_Axial_DIN0207_L6.3mm_D2.5mm_P10.16mm_Horizontal
R16, R21: 10k; PinHeader_1x03_P2.54mm_Vertical
R17: 10; R_Axial_DIN0207_L6.3mm_D2.5mm_P10.16mm_Horizontal
R18: 20k; R_Axial_DIN0207_L6.3mm_D2.5mm_P10.16mm_Horizontal
R20, R24: 30k; R_Axial_DIN0207_L6.3mm_D2.5mm_P10.16mm_Horizontal
R23: 680; R_Axial_DIN0207_L6.3mm_D2.5mm_P10.16mm_Horizontal
R25, R26: 15k; R_Axial_DIN0207_L6.3mm_D2.5mm_P10.16mm_Horizontal
VD1, VD2: 1N4148; D_DO-35_SOD27_P7.62mm_Horizontal
VD3: KB168_NM; D_DO-35_SOD27_P7.62mm_Horizontal
VD4: BZX55C3V3; D_DO-35_SOD27_P7.62mm_Horizontal
VT1, VT6: 2N3906; TO-92_Inline
VT2: S9018; TO-92_Inline
VT3, VT4, VT5: BC547; TO-92_Inline

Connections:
+9V: C5.1, DA2.6, R2.1, R19.1, R27.1
GND: BA1.1, C1.2, C2.1, C4.2, C5.2, C13.1, C14.1, C16.1, C17.1, C21.2, C24.1, C25.1, C26.2, DA2.2, DA2.4, L1.1, L2.2, R13.1, R14.1, R15.1, R16.1, R17.1, R18.2, R21.1, R24.1, VD1.1, VD3.1, VD4.1, VT2.3, VT3.3, VT5.3
unnamed: AE1.1 (A_1), C6.2
unnamed: BA1.2, C12.2
unnamed: C1.1, C2.2, C3.2, R1.2, R3.2, R4.2, R5.2, R6.2
unnamed: C3.1, C8.1, R5.1, VT2.2
unnamed: C4.1, R1.1, R2.2, R7.2, R8.2, R9.2, R10.2
unnamed: C8.2, R11.1
unnamed: C9.1, R8.1, VT4.2
unnamed: C9.2, R9.1, VT5.1
unnamed: C10.1, VD1.2, VD2.1
unnamed: C10.2, R10.1, VT5.2
unnamed: C11.1, C17.2, R15.2, R26.1, VD2.2
unnamed: C11.2, R16.2
unnamed: C12.1, C18.1, DA2.5
unnamed: C6.1, C13.2, R3.1, R4.1, R13.2, VT1.1, VT1.3
unnamed: C7.2, C14.2, C15.2, L1.2, VT1.2
unnamed: C7.1, C15.1, R6.1, VT2.1
unnamed: C16.2, R12.1, R14.2, VT4.3
unnamed: C18.2, R17.2
unnamed: C19.1, C23.2, R23.2, VT6.3
unnamed: C19.2, C20.2, L2.1, VT6.2
unnamed: C20.1, CD1.2, R20.2
unnamed: C21.1, R20.1, R21.3
unnamed: C22.1, C23.1, C24.2, R22.1, R23.1, R27.2, VD4.2
unnamed: C22.2, R18.1, R22.2, VT6.1
unnamed: C25.2, CD1.1, R24.2, R25.2
unnamed: C26.1, R25.1, R26.2
unnamed: DA2.3, R16.3
unnamed: R7.1, VT3.2, VT4.1
unnamed: R11.2, R12.2, VT3.1
unnamed: R19.2, R21.2, VD3.2
